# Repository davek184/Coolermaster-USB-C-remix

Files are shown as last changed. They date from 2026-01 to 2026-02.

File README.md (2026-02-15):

# Coolermaster-USB-C-remix

USB-C daughterboard for Cooler Master NovaTouch keyboards

Manufacturers are charging a large setup fee for assembly of the [original version](https://github.com/davek184/CoolerMasterUsbC) along with tariffs, generally prefer the original version, but remixing for a more affordable option.

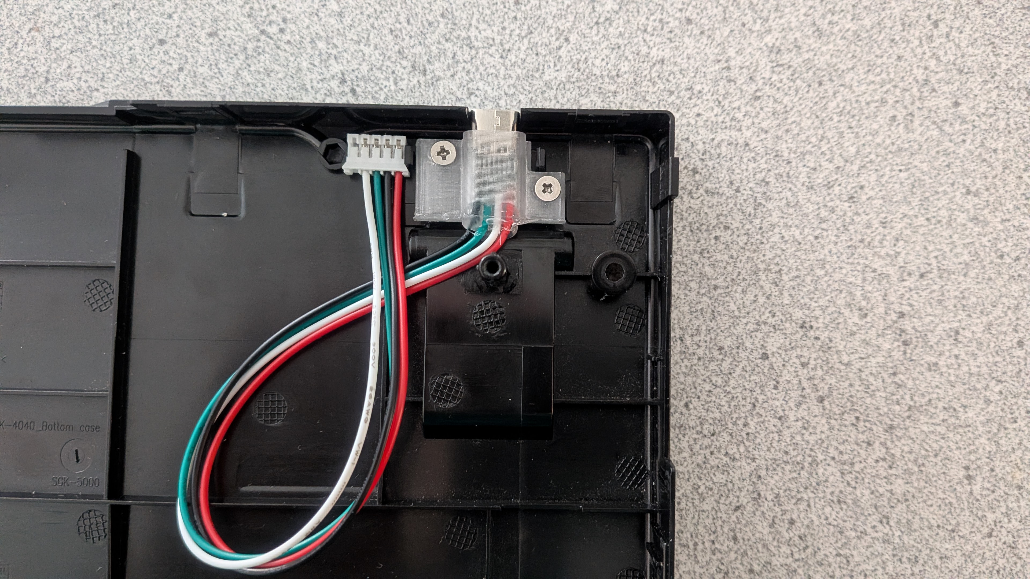
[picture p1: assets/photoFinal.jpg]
Render


Wiring
----
- Blank/Shield (Yellow)
- D- (White)
- D+ (Green)
- GND (Black)
- 5V (Red)

Note: Other Cooler master keyboards may have a different pinnout

Parts
-----
- USB-C breakout board *(female)* [Amazon](https://www.amazon.com/dp/B09WCSF8FC?psc=1&ref_=cm_sw_r_cp_ud_ct_GT8ZEJJ0JSE9TSRHDTRX), [Adafruit](https://www.adafruit.com/product/5180)
- 5.1 Ohm resistor *(package size: 0402 (or prefered 0805, solder: surface)*
- JST PH cable *(wires: 5, length: 150mm)* [Amazon](https://www.amazon.com/dp/B0BKSNJGQL?psc=1&ref_=cm_sw_r_cp_ud_ct_QFTQSGYQR8YCQEH24Z3N), [Adafruit](https://www.adafruit.com/product/5089) 
- 3d printed bracket

Tools
-----
- Soldering iron
- Multimeter
- Hot glue gun
- 3d printer (or order from online service)

3d Print Bracket
-----
Cooler Master NovaTouch
- [Bracket with access hole (recommended)](/3d/coolermaster-novatouch-usbc-bracket-accessHole.stl)
- [Bracket without access hole](/3d/coolermaster-novatouch-usbc-bracket.stl)
Printing
- Orientation: Vertical
- Brim: Full or Mouse Ear
- Material: PETG *suggested*

[TinkerCad design](https://www.tinkercad.com/things/gupjL9dNZFy-coolermaster-usb-c-bracket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)

Assembly 
-----
- Solder cable to beakout board (Skip shield wire or combine it with ground)
- Solder 5.1 ohm resistor if USB C to C cable compatibility desired (this is not an trivial solder job).  [Similar solder details](https://electronics.stackexchange.com/questions/595590/jrc-b008-for-usb-c-microcontroller-power-supply/601047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)
- Test cable with multimeter to ensure there are no shorts!
- Test cable with keyboard
- Push daughterboard into 3d print (use a flat head screwdriver and the access hold in the bottom for alighnment). Dry fit to ensure in a good position.  
- Hot glue breakout board to 3d printed bracket
- Install in keyboard

Notes
----
- Norbatouch unsure of compatibility
- Soldering 5.1 ohm resistor is not the easiest thing to do recommend buying a board that already has it installed. Easier with a larger 0805 size resistor vs the very small 0402.

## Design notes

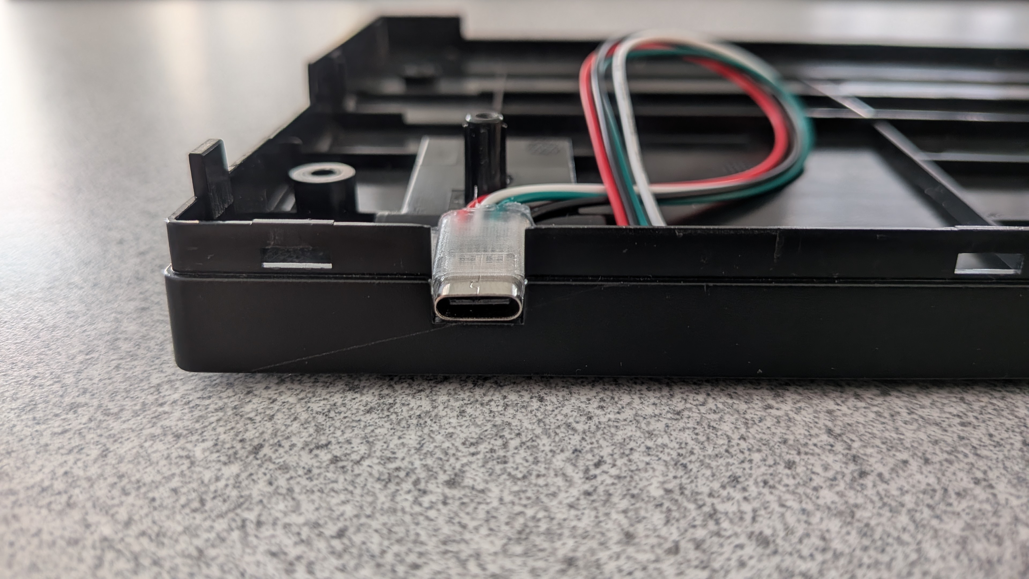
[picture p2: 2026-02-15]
assets/photoFinalOutside.jpg

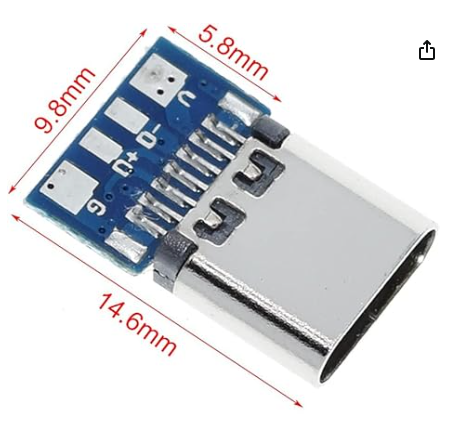
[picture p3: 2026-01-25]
assets/USB-C-Breakout.png

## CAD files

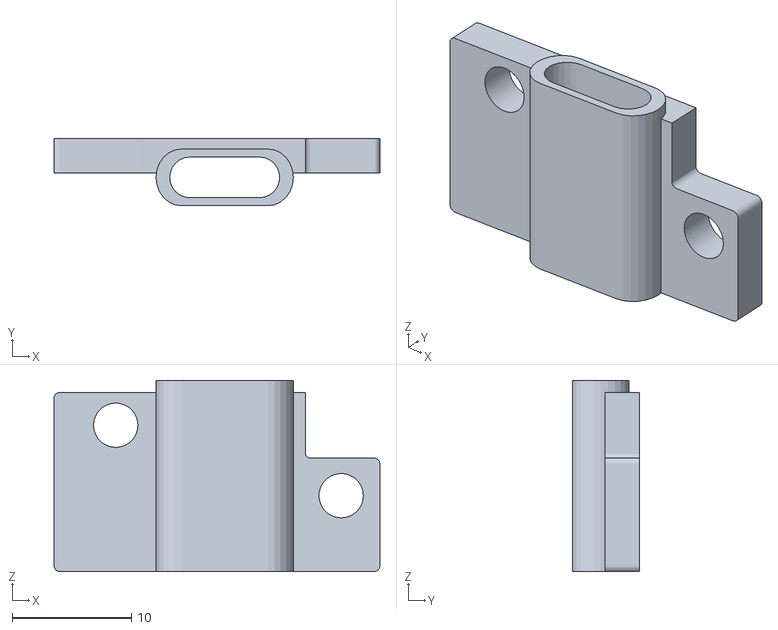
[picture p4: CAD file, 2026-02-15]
3d/coolermaster-novatouch-usbc-bracket-accessHole.stl
27.3 x 5.65 x 16.0

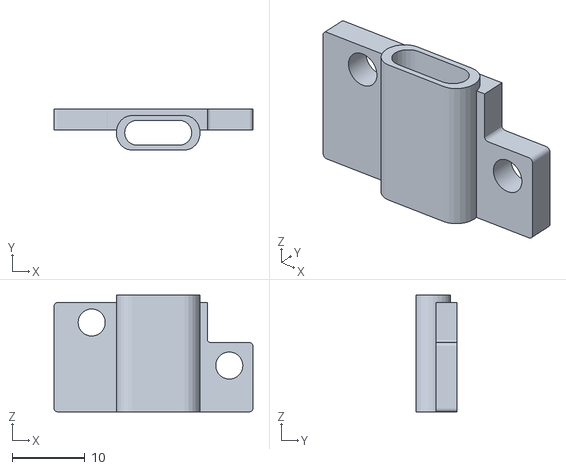
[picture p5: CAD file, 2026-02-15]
3d/coolermaster-novatouch-usbc-bracket.stl
27.3 x 5.65 x 16.0

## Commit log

2026-01-25 Initial Assets and readme
    [Novatouch Coolermaster USB-C bracket.stl, coolermaster-novatouch-usbc-bracket-accessHole.stl, coolermaster-novatouch-usbc-bracket.stl]
2026-01-25 Add STL file link for 3D printed bracket
2026-01-26 Update README with 3D printed bracket information
    Added details about 3D printed brackets for Coolermaster Novatouch.
2026-01-26 Revise parts list and include 3D printing details
    Updated parts list and added printing instructions.
2026-01-26 Update README with installation and wiring details
    Added wiring instructions and clarified installation steps.
2026-02-15 Updating bracket and instructions
    [coolermaster-novatouch-usbc-bracket-accessHole.stl, coolermaster-novatouch-usbc-bracket.stl]
2026-02-15 Update README with new bracket links and image
    Updated links for 3D print brackets and added an image.
2026-02-15 Add wiring section and compatibility note to README
    Added wiring details for USB-C connections and noted potential pinout differences for Cooler Master keyboards.
